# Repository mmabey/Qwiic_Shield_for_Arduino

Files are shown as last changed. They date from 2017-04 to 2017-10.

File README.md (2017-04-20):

Qwiic Shield for Arduino
========================================

Qwiic_Shield_for_Arduino

[*SPX-14286*](https://www.sparkfun.com/products/14286)

Uno compatible shield to connect I2C pins to 4 ports of I2C connectors. Includes level translation.

License Information
-------------------

This product is _**open source**_!

Please review the LICENSE.md file for license information.

If you have any questions or concerns on licensing, please contact techsupport@sparkfun.com.

Distributed as-is; no warranty is given.

- Your friends at SparkFun.

_<COLLABORATION CREDIT>_

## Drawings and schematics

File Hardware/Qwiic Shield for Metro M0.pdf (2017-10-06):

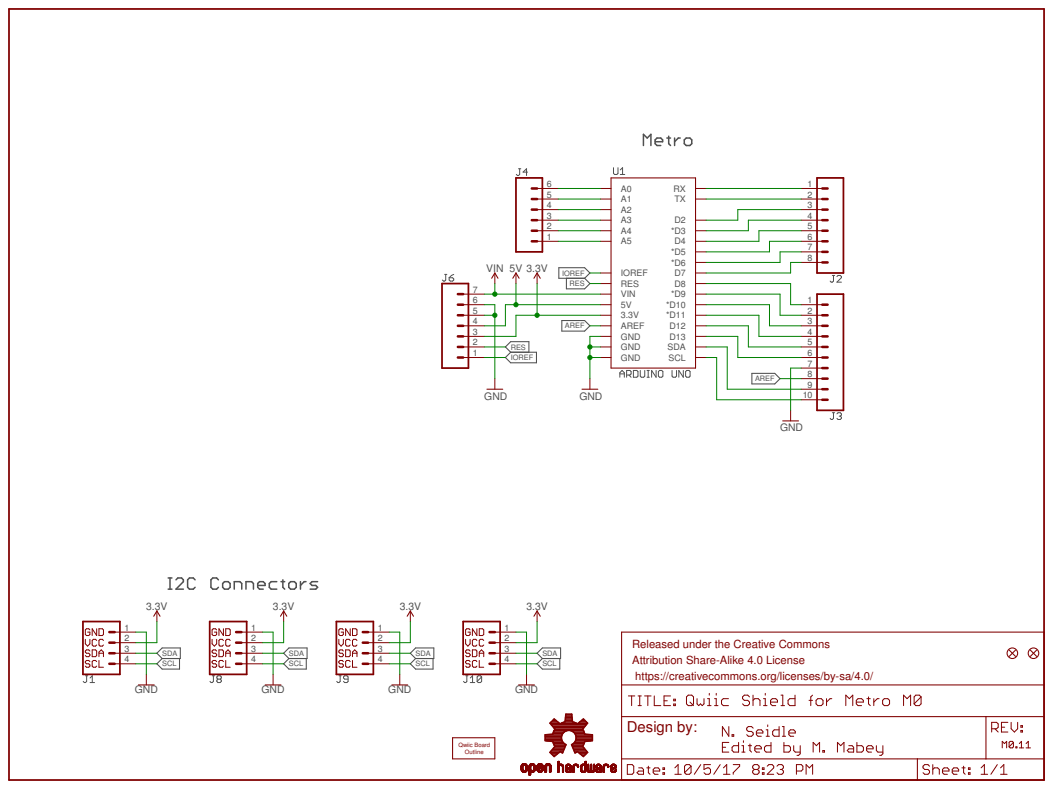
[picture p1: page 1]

Released under the Creative Commons Attribution Share-Alike 4.0 License

https://creativecommons.org/licenses/by-sa/4.0/

Design by: Qwiic Board Outline

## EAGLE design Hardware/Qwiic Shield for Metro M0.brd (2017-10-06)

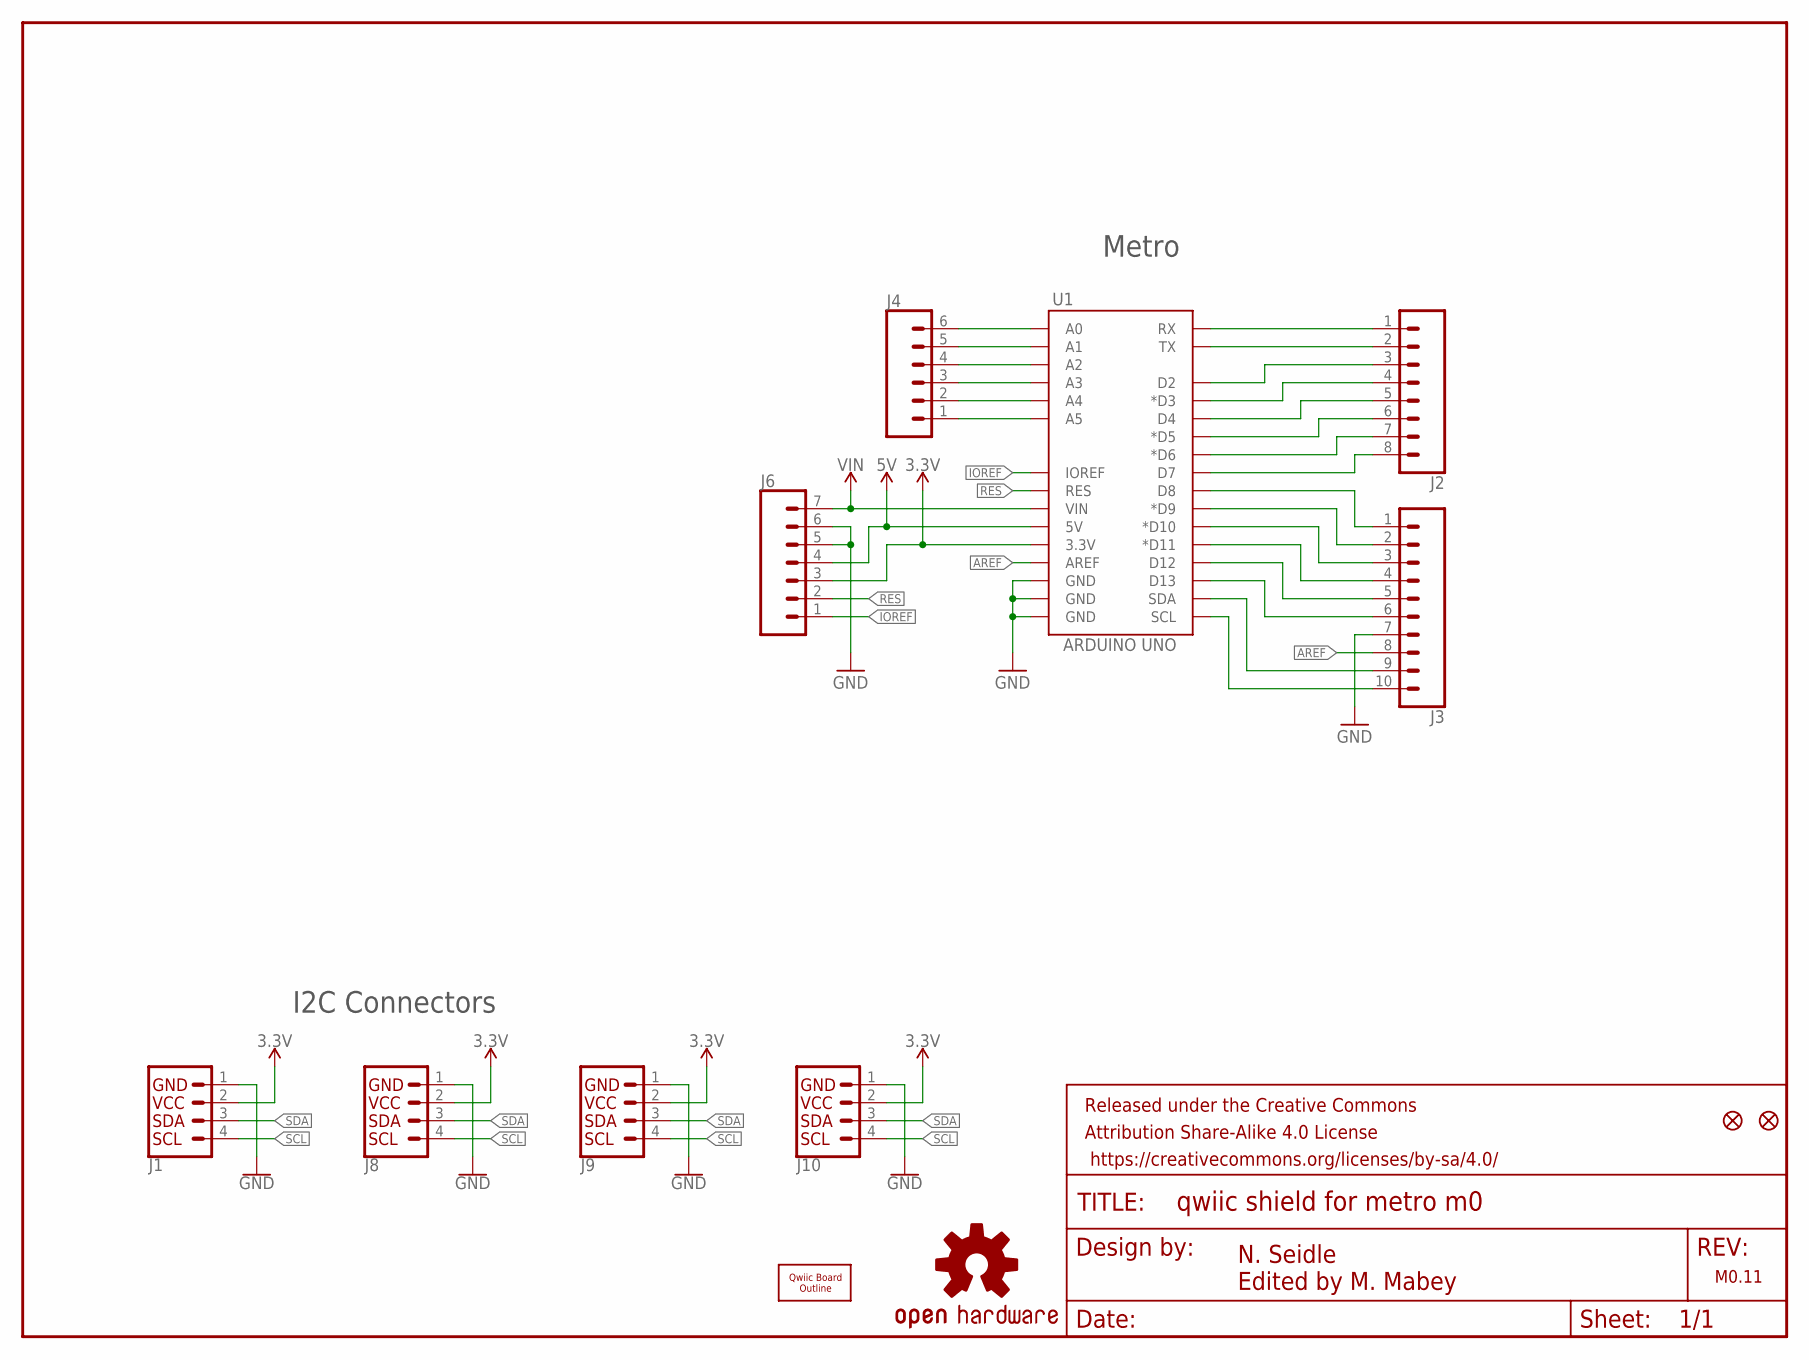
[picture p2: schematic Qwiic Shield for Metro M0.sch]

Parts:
FD1, FD2: FIDUCIAL1X2; FIDUCIAL-1X2
FRAME1: FRAME-LETTER; CREATIVE_COMMONS
J1, J8, J9, J10: I2C_STANDARDJS-1MM; 1X04_1MM_RA
J2: CONN_08NO_SILK_FEMALE_PTH; 1X08_NO_SILK
J3: CONN_10NO_SILK_PTH_FEMALE; 1X10_NO_SILK
J4: CONN_06NO_SILK_FEMALE_PTH; 1X06_NO_SILK
J6: CONN_07NO_SILK; 1X07_NO_SILK
LOGO1: OSHW-LOGOMINI; OSHW-LOGO-MINI
U1: ARDUINO UNO; UNO_R3_SHIELD_NOLABELS
U$3: QWIIC_BOARD_OUTLINEH; QWIIC_BOARD_MOUNT_HOLES

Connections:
3.3V: J1.2 (VCC), J6.3, J8.2 (VCC), J9.2 (VCC), J10.2 (VCC), U1.3.3V
5V: J6.4, U1.5V
A0: J4.6, U1.A0
A1: J4.5, U1.A1
A2: J4.4, U1.A2
A3: J4.3, U1.A3
A4: J4.2, U1.A4
A5: J4.1, U1.A5
AREF: J3.8, U1.AREF
D2: J2.3, U1.D2
D3: J2.4, U1.D3 (*D3)
D4: J2.5, U1.D4
D5: J2.6, U1.D5 (*D5)
D6: J2.7, U1.D6 (*D6)
D7: J2.8, U1.D7
D8: J3.1, U1.D8
D9: J3.2, U1.D9 (*D9)
D10: J3.3, U1.D10 (*D10)
D11: J3.4, U1.D11 (*D11)
D12: J3.5, U1.D12
D13: J3.6, U1.D13
GND: J1.1 (GND), J3.7, J6.5, J6.6, J8.1 (GND), J9.1 (GND), J10.1 (GND), U1.GND@0 (GND), U1.GND@1 (GND), U1.GND@2 (GND)
IOREF: J6.1, U1.IOREF
RES: J6.2, U1.RES
RX: J2.1, U1.RX
SCL: J1.4 (SCL), J3.10, J8.4 (SCL), J9.4 (SCL), J10.4 (SCL), U1.SCL
SDA: J1.3 (SDA), J3.9, J8.3 (SDA), J9.3 (SDA), J10.3 (SDA), U1.SDA
TX: J2.2, U1.TX
VIN: J6.7, U1.VIN

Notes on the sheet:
N. Seidle Edited by M. Mabey
Metro
M0.11
I2C Connectors

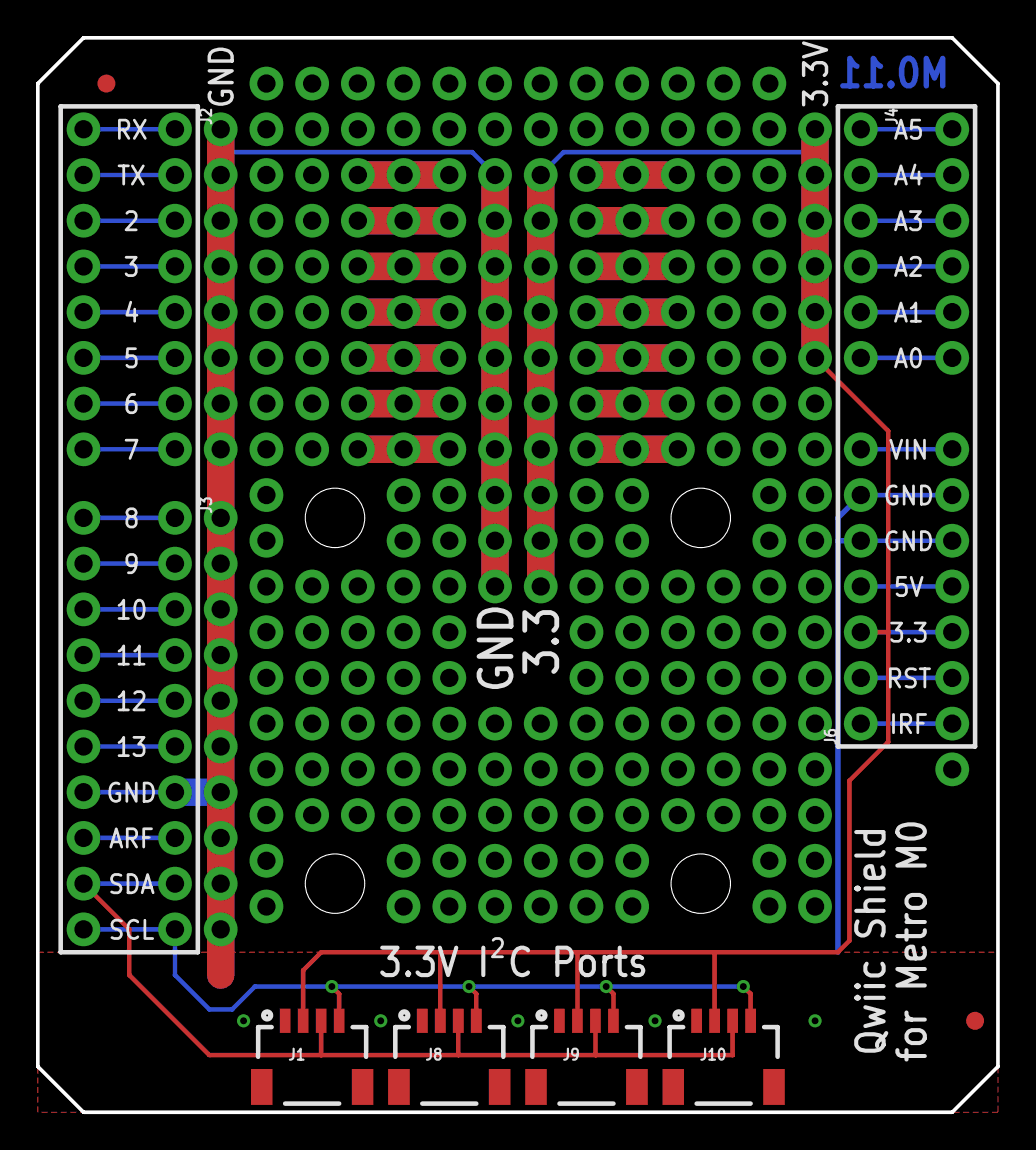
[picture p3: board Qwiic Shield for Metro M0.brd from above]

Board: 2 copper layers, 53.3 x 59.7 mm, 14 parts (1 on the bottom side), 29 nets.

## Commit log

2017-03-07 Initial layout and panel
    [Arduino-I2C-Shield-Panel.GBL, Arduino-I2C-Shield-Panel.GBO, Arduino-I2C-Shield-Panel.GBS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]
2017-03-08 Changing panel to 3mm spacing for v-score
    [Arduino-I2C-Shield-Panel.GBL, Arduino-I2C-Shield-Panel.GBO, Arduino-I2C-Shield-Panel.GBS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]
2017-03-13 Adding Mux Shield
    [Arduino-I2C-Shield-Panel-0.51mm.brd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]
2017-03-13 Breaking out reset pin
    [SparkFun Qwiic Mux Shield with JST.brd, SparkFun Qwiic Mux Shield with JST.sch]
2017-03-24 Cleaning up repo. Adding pdf schematic.
    [Arduino-I2C-Shield-Panel-0.51mm.brd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]
2017-04-03 File rename
    [Qwiic Shield for Arduino.brd, Qwiic Shield for Arduino.sch]
2017-04-14 Adding mounting spot for Qwiic boards
    [Q Arduino Panel.brd, Qwiic Shield for Arduino.brd, Qwiic Shield for Arduino.sch]
2017-04-14 Adding panel
    [Q Arduino Panel.GBL, Q Arduino Panel.GBO, Q Arduino Panel.GBS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]
2017-04-17 Adding Qwiic mounting holes to shield
    [Qwiic Shield for Arduino.brd, Qwiic Shield for Arduino.sch]
2017-09-17 Updated board/schematic
    Changes are mostly to make the shield compatible with 3.3V logic
    microcontrollers. This means there's no need for the level shifting
    between the shield and the MCU. Also, the power lines are all connected
    to the 3.3V pin instead of 5V.
    [Q Arduino Panel.GBL, Q Arduino Panel.GBO, Q Arduino Panel.GBS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]
2017-10-06 Re-routed board to use SCL/SDA instead of A4/A5
    The Metro Express M0 cannot use A4/A5 as SCL/SDA, so the previous
    version of the shield was completely incompatible with the board.
    [Qwiic Shield for Metro M0.brd, Qwiic Shield for Metro M0.sch]

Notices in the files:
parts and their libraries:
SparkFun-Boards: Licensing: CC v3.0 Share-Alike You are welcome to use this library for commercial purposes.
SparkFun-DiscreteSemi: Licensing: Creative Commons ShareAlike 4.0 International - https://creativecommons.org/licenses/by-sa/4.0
